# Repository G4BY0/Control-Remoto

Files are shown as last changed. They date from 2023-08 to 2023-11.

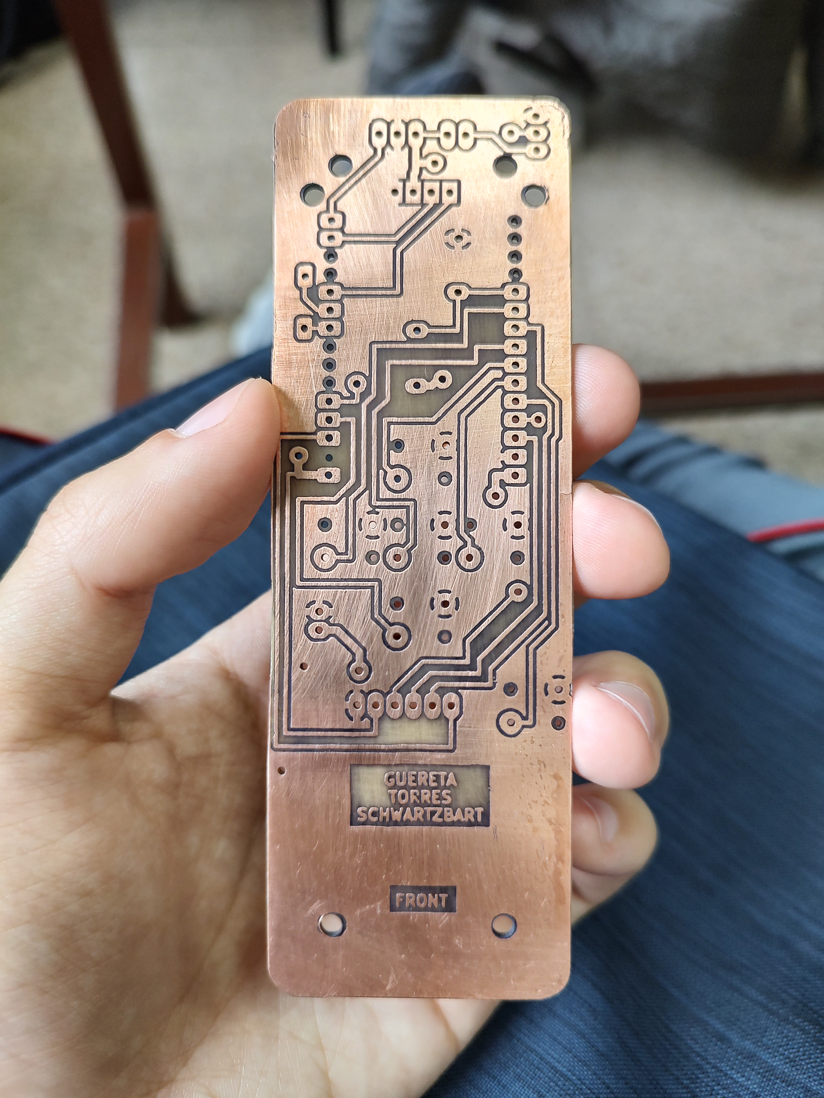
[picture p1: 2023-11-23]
hardware/PCB (KiCAD)/Front.jpg

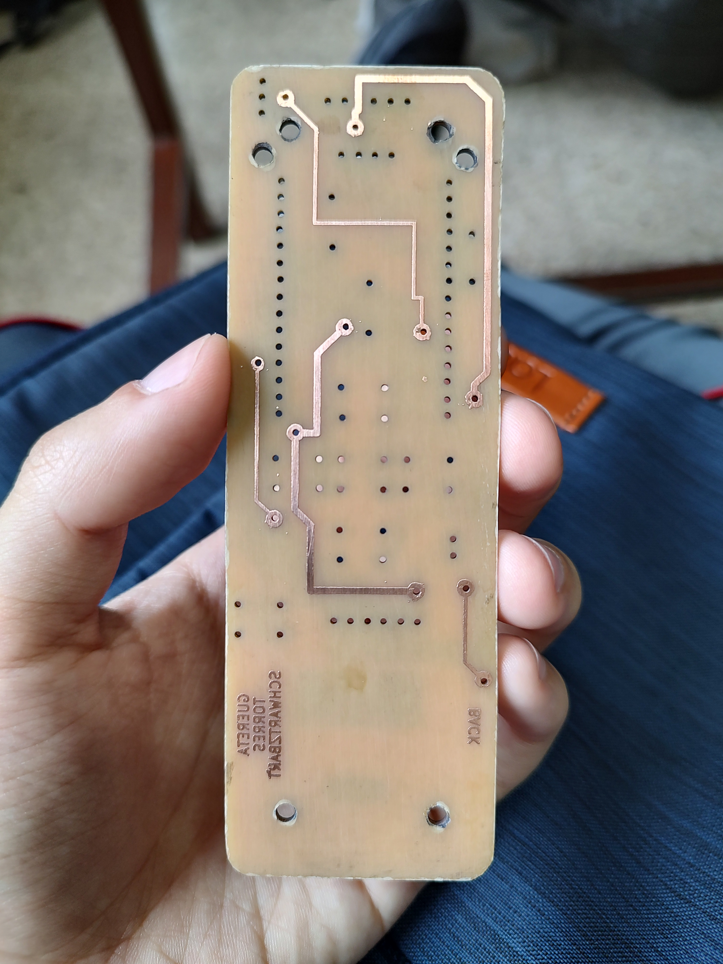
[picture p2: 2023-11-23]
hardware/PCB (KiCAD)/Back.jpg

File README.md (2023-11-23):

# Remote Controller

### A literal super universal remote controller, you can manipulate TVS, AIR CONDITIONERS, DECODERS and MORE.

The purpose of this project is to have in one room, one infrared remote for everything.

https://github.com/G4BY0/Control-Remoto/blob/af7007d788a45e271489a508236b302a6bf80a4f/Picture.jpeg

## Contents

  -[How it works?](#how-it-works?)
  -[Development Status](#development-status)
  -[Hardware](#hardware)
  -[Dependencies](#dependencies)

## How it works? (Software)

The structure of the stored Infrared signals is:

Example:

* Profile: LG TV
* Subprofile: Turn on

This kind of profiles are stored on the SD, they are separated in diferent files.

Example: LG_TV.db

This files have the binary of infrared signals with the name of their subprofiles.

## Development Status

Latest Stable Release    

Latest Development Release    

## Hardware

* [PCB](https://github.com/G4BY0/Control-Remoto/tree/main/hardware)
* Display Adafruit SH110X
* Six Botons
* [Nodemcu Esp32-S (4MB Flash Memory)](https://docs.ai-thinker.com/_media/esp32/docs/nodemcu-32s_product_specification.pdf)
* Module SD (3.3V, We modded it to work with that voltage)
* BC548 (Battery Medition)
* VS1838 (Infrared Receiver)
* Infrared LED (Infrared Emitter)
* LIPO Battery 3.7-4.2V
* Step Up 1.8v-4.2v to 5V (180mA)
* LIPO Charger USB-C Port
* 2N3904
* Resistors 10K, 10K, 630K (Battery Medition)
* [Six Keycaps](https://github.com/G4BY0/Control-Remoto/tree/main/hardware/STL's)
* [Case](https://github.com/G4BY0/Control-Remoto/tree/main/hardware/STL's)
* Cable USB-C for charging

## Dependencies

* [Adafruit BusIO](https://github.com/adafruit/Adafruit_BusIO)
* [Adafruit GFX Library](https://github.com/adafruit/Adafruit-GFX-Library)
* [Adafruit SH110X](https://github.com/adafruit/Adafruit_SH110x)
* [QRCode](https://www.adafruit.com/products/2471)
* [arduino-esp32](https://www.adafruit.com/products/2471)

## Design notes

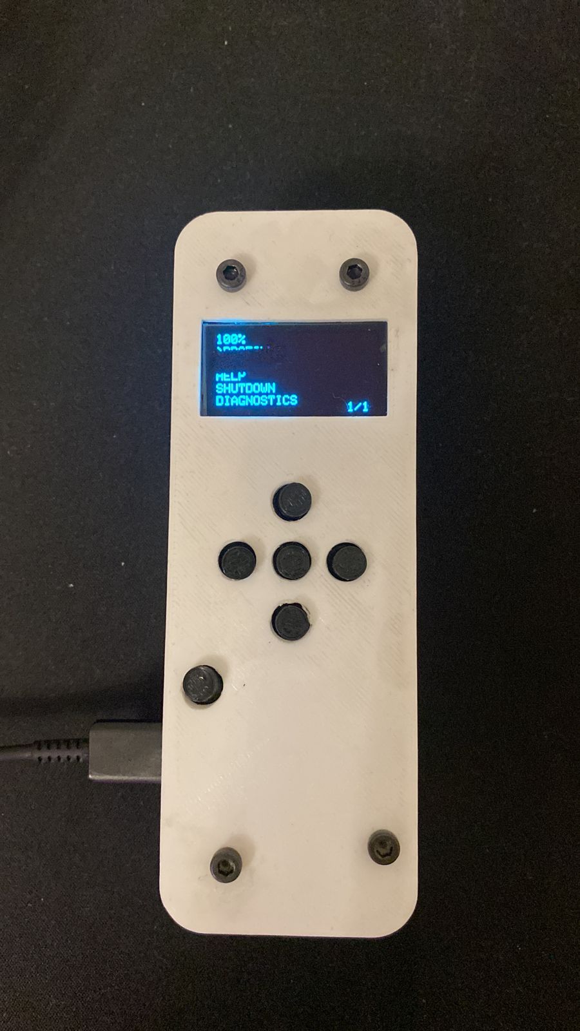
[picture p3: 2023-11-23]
Picture.jpeg

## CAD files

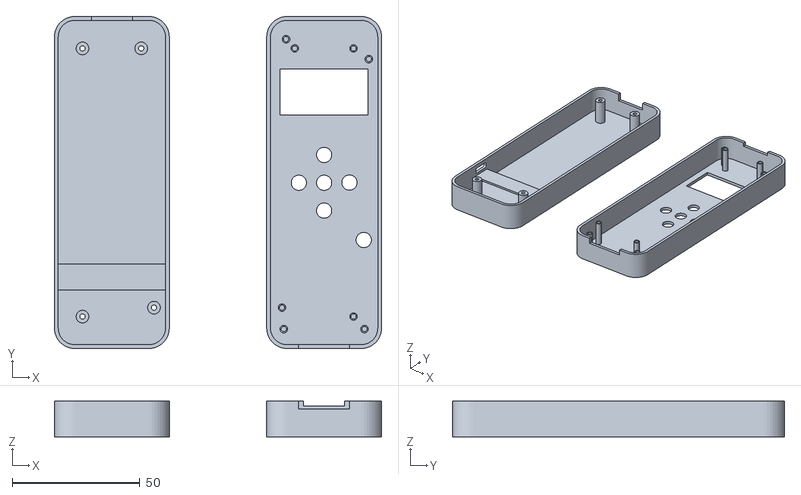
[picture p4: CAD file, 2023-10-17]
hardware/CASE/Gabinete.stl
128.1 x 130.0 x 14.0

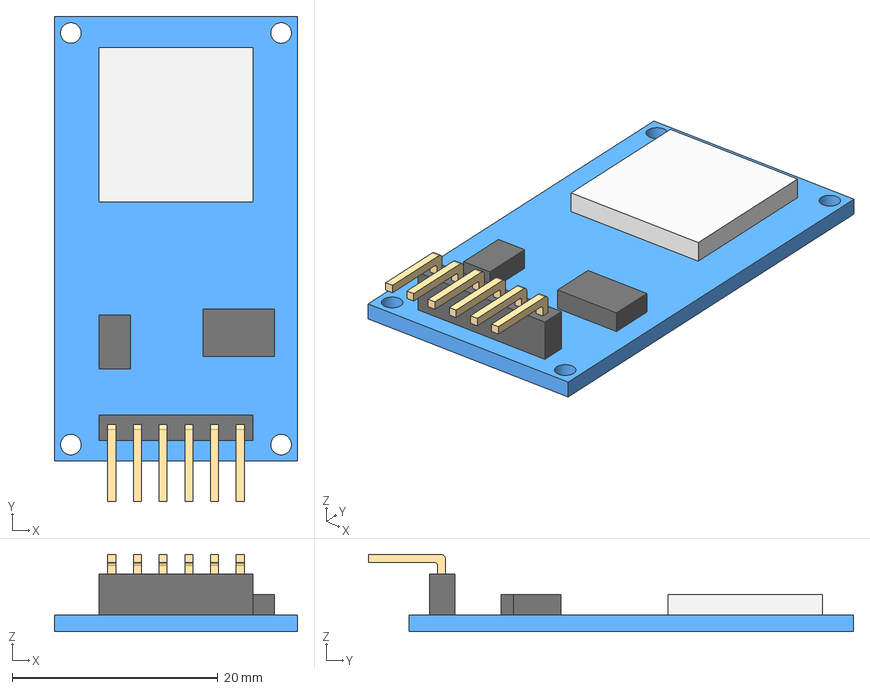
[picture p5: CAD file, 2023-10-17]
hardware/PCB (KiCAD)/modelos/micro_sdCard.step
23.6 x 47.1 x 7.50 mm

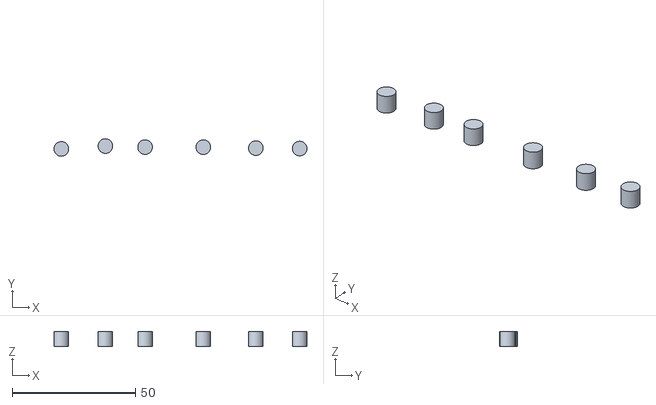
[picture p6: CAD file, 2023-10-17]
hardware/CASE/Keycaps.stl
102.7 x 7.11 x 6.00

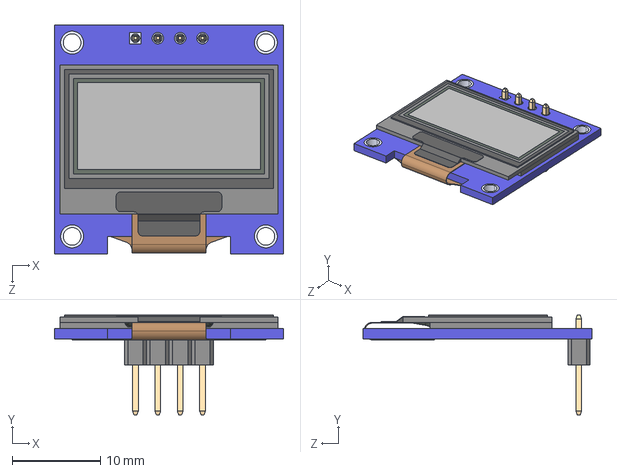
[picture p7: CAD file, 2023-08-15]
hardware/PCB (KiCAD)/modelos/DM-OLED096-636--3DModel-STEP-56544.STEP
26.0 x 11.3 x 26.0 mm
DM-OLED096-636_Module
DM-OLED096-636_Panel

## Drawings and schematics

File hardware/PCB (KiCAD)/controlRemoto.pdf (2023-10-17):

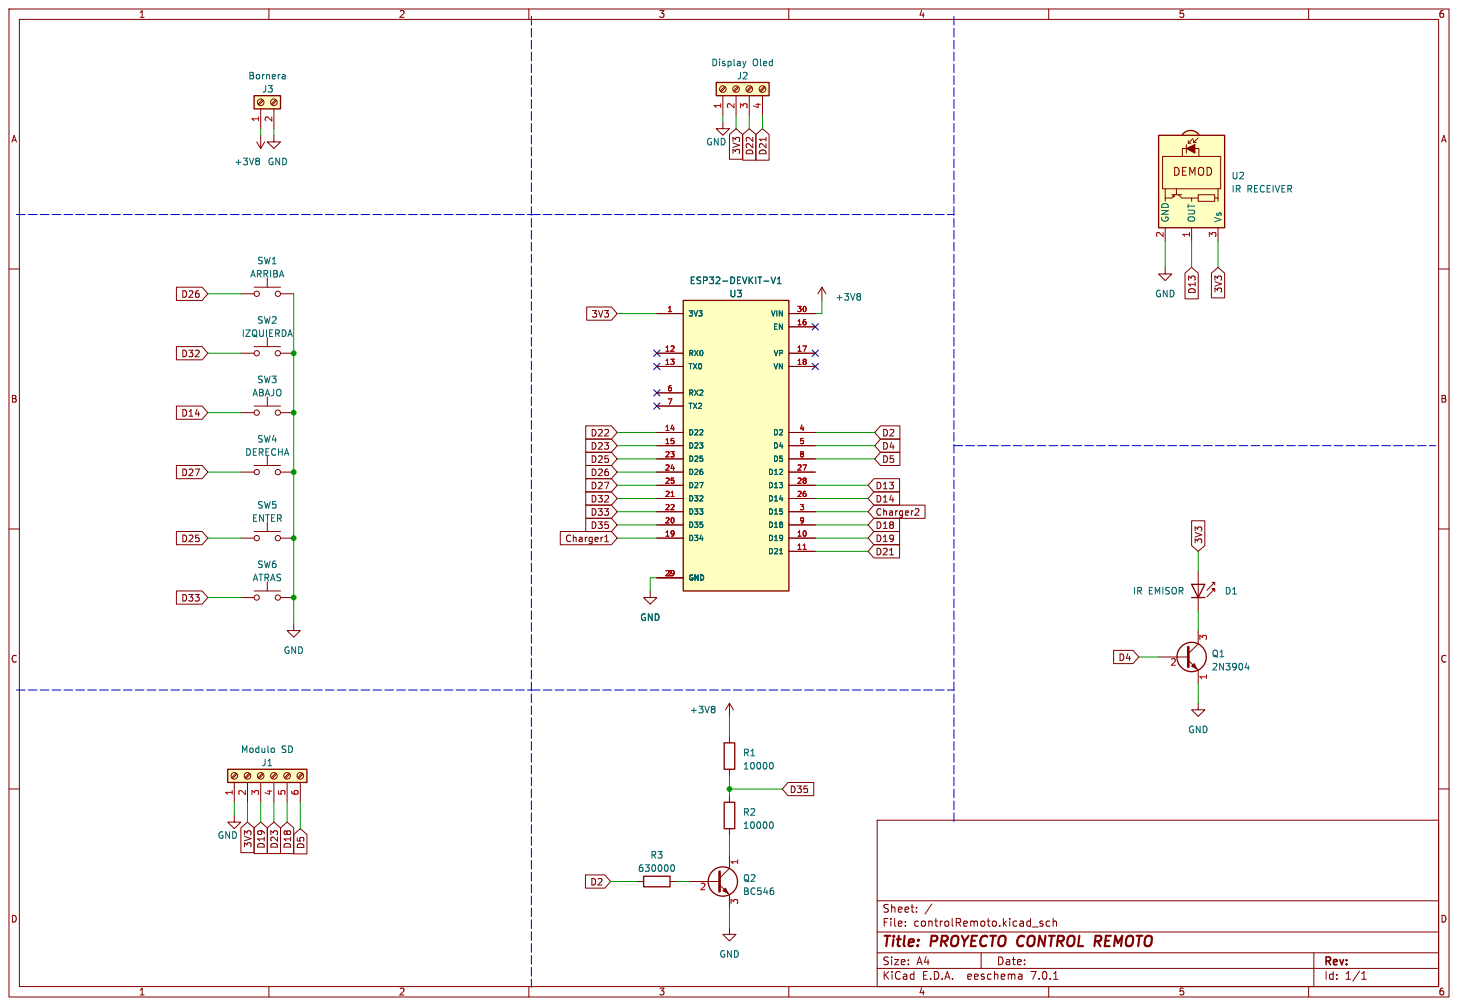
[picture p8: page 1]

File: controlRemoto.kicad_sch Sheet: / SW5 ENTER

Id: 1/1 Title: PROYECTO CONTROL REMOTO

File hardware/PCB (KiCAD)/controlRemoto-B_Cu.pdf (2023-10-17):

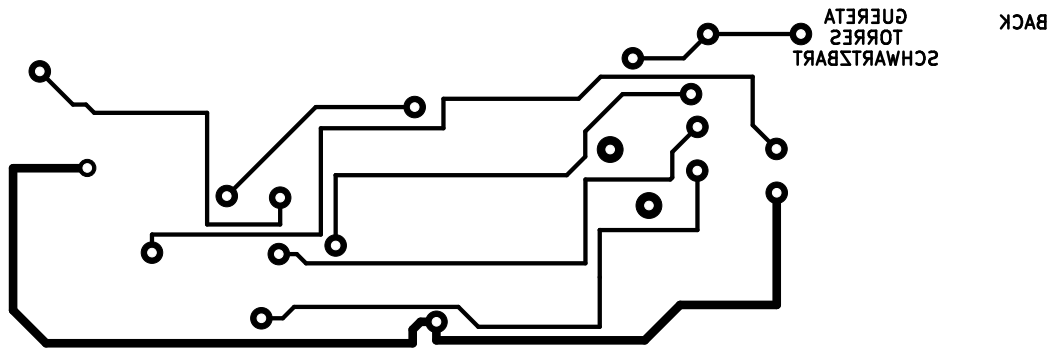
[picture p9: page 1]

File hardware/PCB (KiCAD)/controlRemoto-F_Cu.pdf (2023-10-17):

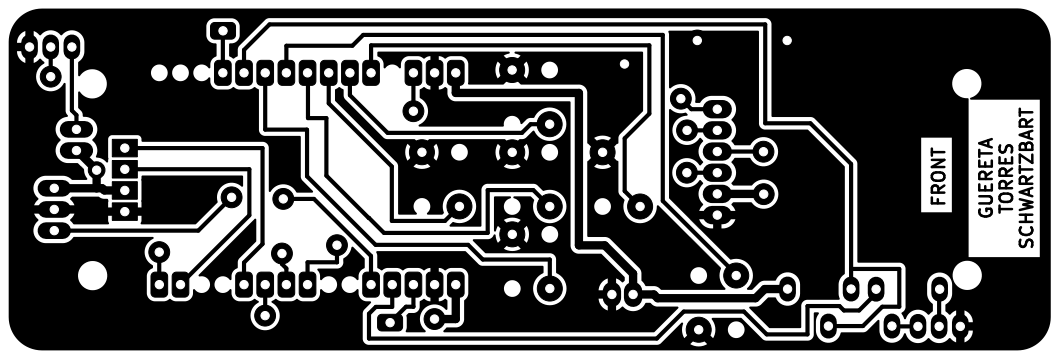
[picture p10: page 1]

GUERETA TORRES SCHWARTZBART FRONT

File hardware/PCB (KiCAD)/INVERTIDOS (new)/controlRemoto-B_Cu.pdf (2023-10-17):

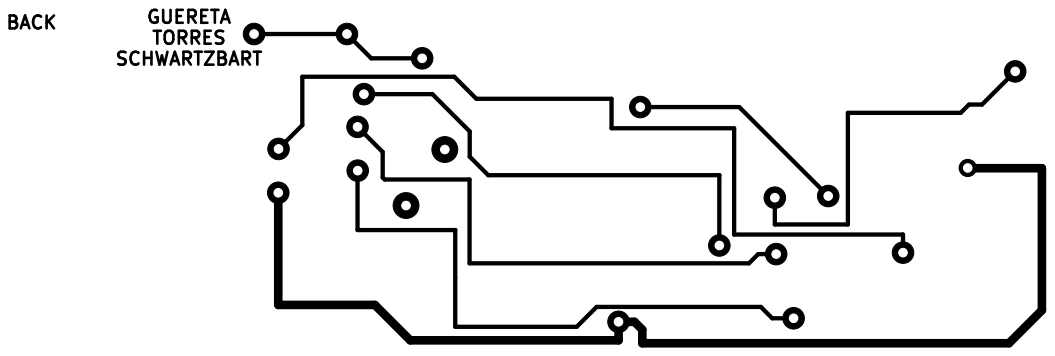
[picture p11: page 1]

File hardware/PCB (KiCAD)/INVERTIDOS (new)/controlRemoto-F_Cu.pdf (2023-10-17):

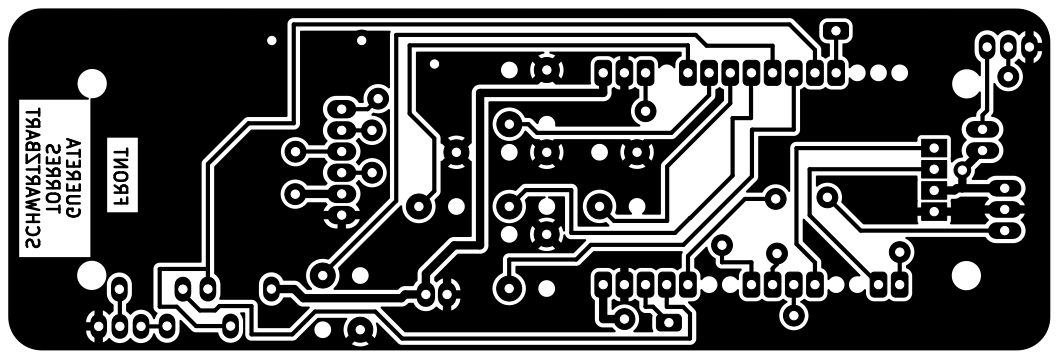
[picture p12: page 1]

TORRES GUERETA SCHWARTZBART FRONT

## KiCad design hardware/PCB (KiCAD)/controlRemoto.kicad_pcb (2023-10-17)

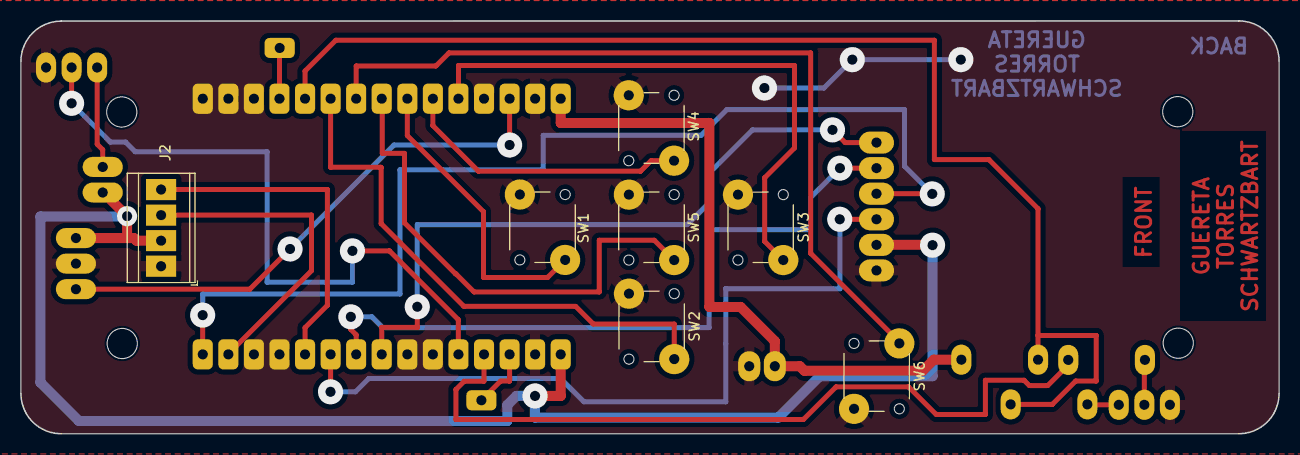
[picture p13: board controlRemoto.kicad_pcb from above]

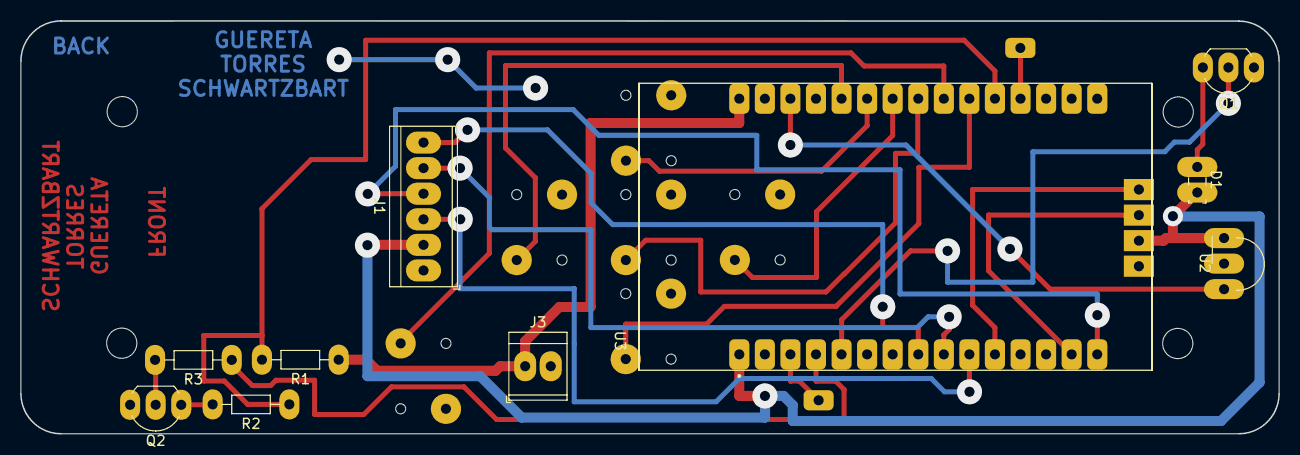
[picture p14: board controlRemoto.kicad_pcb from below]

Board: 2 copper layers, 125.0 x 41.0 mm, 17 parts (10 on the bottom side), 22 nets.

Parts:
D1: IR EMISOR; LED_SideEmitter_Rectangular_W4.5mm_H1.6mm
J1: Modulo SD; TerminalBlock_TE_282834-6_1x06_P2.54mm_Horizontal
J2: Display Oled; TerminalBlock_TE_282834-4_1x04_P2.54mm_Horizontal
J3: Bornera; TerminalBlock_TE_282834-2_1x02_P2.54mm_Horizontal
Q1: 2N3904; TO-92_Inline_Wide
Q2: BC546; TO-92_Inline_Wide
R1, R2: 10000; R_Axial_DIN0204_L3.6mm_D1.6mm_P7.62mm_Horizontal
R3: 630000; R_Axial_DIN0204_L3.6mm_D1.6mm_P7.62mm_Horizontal
SW1: ARRIBA; SW_PUSH_6mm_H4.3mm
SW2: IZQUIERDA; SW_PUSH_6mm_H4.3mm
SW3: ABAJO; SW_PUSH_6mm_H4.3mm
SW4: DERECHA; SW_PUSH_6mm_H4.3mm
SW5: ENTER; SW_PUSH_6mm_H4.3mm
SW6: ATRAS; SW_PUSH_6mm_H4.3mm
U2: IR RECEIVER; Vishay_MINIMOLD-3Pin
U3: ESP32-DEVKIT-V1; MODULE_ESP32_DEVKIT_V1

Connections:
3V3: D1.2 (A), J1.2, J2.2, U2.3 (Vs), U3.1 (3V3)
+3V8: J3.1, R1.1, U3.30 (VIN)
D2: R3.1, U3.4 (D2)
D4: Q1.2 (B), U3.5 (D4)
D5: J1.6, U3.8 (D5)
D13: U2.1 (OUT), U3.28 (D13)
D14: SW3.1, U3.26 (D14)
D18: J1.5, U3.9 (D18)
D19: J1.3, U3.10 (D19)
D21: J2.4, U3.11 (D21)
D22: J2.3, U3.14 (D22)
D23: J1.4, U3.15 (D23)
D25: SW5.1, U3.23 (D25)
D26: SW1.1, U3.24 (D26)
D27: SW4.1, U3.25 (D27)
D32: SW2.1, U3.21 (D32)
D33: SW6.1, U3.22 (D33)
D35: R1.2, R2.1, U3.20 (D35)
GND: J1.1, J2.1, J3.2, Q1.1 (E), Q2.3 (E), SW1.2, SW2.2, SW3.2, SW4.2, SW5.2, SW6.2, U2.2 (GND), U3.2 (GND), U3.29 (GND)
unnamed: D1.1 (K), Q1.3 (C)
unnamed: Q2.2 (B), R3.2
unnamed: Q2.1 (C), R2.2

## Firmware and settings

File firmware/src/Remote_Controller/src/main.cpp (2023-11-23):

//Copyright Grupo 11, Inc. All Rights Reserved.
/***********************************************
 * * * * * * * * * * * * * * * * * * * * * * * *
 * \file
 * Main.cpp (Main File)
 * 
 * * * * * * * * * * * * * * * * * * * * * * * *
***********************************************/
#warning "Project is in developing, it's not already yet!"

#include <Arduino.h>
#include <Wire.h>               // I2C
#ifdef ESP32
#include <Wifi.h>
#elif ESP8266
#include <ESP8266WiFi.h>
#endif
#include <NTPClient.h>
#include <WiFiUdp.h>
#define WIFI_ON

#include <SPI.h> 
#include "System.h"
#include "Storage/Config.h"
#include "Modes/Modes.h"

#define DEBUG

SPIClass spi; // Medio de Comunicacion con el Almacenamiento

//Velocidad del Monitor Serial
#define SERIAL_BAUDRATE 115200
//Frecuencia de Actualizacion del Clock (En Milisegundos)
#define REFRESH_CLOCK 500 
// Retocar macro en caso de querer establecer cuanto se pone el modo apagado luego de estar ese tiempo en el modo SLEEPING (En Segundos)
#define SLEEP_TIME_WAITING_TO_SHUTDOWN (5U * 60U)   // 5 minutos en segundos

// Retocar macro en caso de querer establecer cuanto tiempo el usuario debe mantener el boton back para poner el modo SLEEPING (En Segundos)
#define SLEEP_TIME_BUTTONPRESSING (5U)

#define CLOCK_ON
#define WIFI_ON  
//#define BLUETOOTH_ON

#define SSID_IN         "TP-LINK_4F48"        //SSID del access point en el que se conectara el servicio WiFi
#define PASSWORD_IN     "51807511"            //PASSWORD del access point en el que se conectara el servicio WiFi

//(Desarrollo) Pagina Web
#define SSID_OUT        "Remote_Controller"   //SSID del access point que se generara
#define PASSWORD_OUT    "Authors:GMJ"       //PASSWORD del access point que se generara

void setup(){
    
    Serial.begin(SERIAL_BAUDRATE , SERIAL_8N1 );

    // Configuracion de protocolo de comunicacion para el almacenamiento
    spi=SPIClass(VSPI); 
    spi.begin();
    
    // Inicializacion del sistema del display
    displayBegin();     Serial.println(F("Display Inicializado."));

    // Inicializacion del sistema de botones
    buttonsBegin();     Serial.println(F("Botonera Inicializada."));

    // Inicializacion del sistema de almacenamiento
    SDBegin();          Serial.println(F("Almacenamiento Inicializado."));

    // Inicializacion del sistema del infrarrojo
    infraredBegin();    Serial.println(F("Infrared Inicializado."));
    
    // configSaved(); // (Canceled) De momento cancelado hasta nuevo aviso

    // Espero a que todos los procesos terminen para inicializar
    Serial.flush(); yield();
    /*
    // Task para correr el programa principal
    xTaskCreate(
        Task_Idle,                      // Funcion codigo del Task
        "Task_Idle",                    // Nombre del Task 
        100024U,                        // Reserva de espacio en la Pila
        NULL,                           // Argumentos
        tskIDLE_PRIORITY,               // Prioridad
        &handleIdle                     // Handle 
    );
    */
    // Crear tarea del Watchdog Timer
    xTaskCreate(
        Task_WatchDogTimer,             // Funcion codigo del Task
        "Task_WatchDogTimer",           // Nombre del Task
        configMINIMAL_STACK_SIZE + 256U,// Reserva de espacio en la Pila
        NULL,                           // Argumentos
        tskIDLE_PRIORITY + 2U,          // Prioridad
        NULL                            // Sin Handle
    );

    // Task para preguntar si el usuario esta activo de forma dinamica 
    xTaskCreate(
        Task_AFK,                       //Funcion codigo del Task
        "Task_AFK",                     //Nombre del Task 
        configMINIMAL_STACK_SIZE + 256U,//Reserva de espacio en la Pila 
        NULL,                           //Argumentos
        tskIDLE_PRIORITY + 1U,          //Prioridad
        &handleSleep                    //Handle   
    );

    // Task para preguntar si se desea un reinicio de emergencia
    xTaskCreate(
        Task_emergencyRestart,              //Funcion codigo del Task
        "Task_AskingForEmergencyRestart",   //Nombre del Task 
        configMINIMAL_STACK_SIZE + 256U,    //Reserva de espacio en la Pila 
        NULL,                               //Argumentos 
        tskIDLE_PRIORITY + 2U,              //Prioridad
        NULL                                //Handle   
    );

    UI.show = true;
    UI.show_battery = true;
    UI.show_storage = false;
    UI.run(); // Task para la User Interface

    // Iniciar el scheduler de FreeRTOS
    //vTaskStartScheduler(); // Genera un core dump si se permite el uso del void loop() Asegurarse de usar si es que no se usa el void loop() (Generado por el Watch Dog Timer)

}

//Puesto unicamente por el framework de arduino. El sistema esta montado en Tasks gracias a FreeRTOS
void loop(){ MODE::hub(); } //El Idle esta ubicado en System.h (Programa principal)

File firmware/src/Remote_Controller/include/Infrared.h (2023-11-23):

//Copyright Grupo 11, Inc. All Rights Reserved.
/***********************************************
 * * * * * * * * * * * * * * * * * * * * * * * *
 * \file
 * Manejo de las señales infrarrojas 
 * 
 * * * * * * * * * * * * * * * * * * * * * * * *
***********************************************/
#ifndef INFRARED_H
#define INFRARED_H

#include <Arduino.h>
#include <cstdint>
#include <memory>
#include <algorithm>
#include "PIN.h"
#include <IRsend.h>
#include <IRrecv.h>
#include <IRremoteESP8266.h> // Tambien tiene soporte para placas espressif32!
#include <IRutils.h>

#include "PIN.h"

// The GPIO an IR detector/demodulator is connected to. Recommended: 14 (D5)
// Note: GPIO 16 won't work on the ESP8266 as it does not have interrupts.
// Note: GPIO 14 won't work on the ESP32-C3 as it causes the board to reboot.
constexpr uint16_t kRecvPin = PIN::InfraredReceiver::DATA;
// GPIO to use to control the IR LED circuit. Recommended: 4 (D2).
constexpr uint16_t kIrLedPin = PIN::InfraredTransmitter::DATA;
// The Serial connection baud rate.
// NOTE: Make sure you set your Serial Monitor to the same speed.
constexpr uint32_t kBaudRate = 115200;
// As this program is a special purpose capture/resender, let's use a larger
// than expected buffer so we can handle very large IR messages.
// i.e. Up to 512 bits.
constexpr uint16_t kCaptureBufferSize = 1024U;
// kTimeout is the Nr. of milli-Seconds of no-more-data before we consider a
// message ended.
constexpr uint8_t kTimeout = 50U;  // Milli-Seconds
// kFrequency is the modulation frequency all messages will be replayed at.
constexpr uint16_t kFrequency = 38000U;  // in Hz. e.g. 38kHz.

// Storage for the recorded code
// Estructura de almacenamiento de datos del infrarrojo
struct storedIRDataStruct {
  decode_results results;
  char nameSubProfile[30] = {'\0'}; // Nombre del subperfil + Inicializacion
};

/*! @brief Inicializacion de infrarrojos
    @note Arduino por defecto establece como entrada los pines digitales*/
void infraredBegin(void);

/*! @brief Inicia el proceso para recibir señales infrarrojas
    @note Crea una estructura que almacena cadena binaria (guardada en hexadecimal), numero de bits, etc  
*/
void Receive_start(void);

/*! @brief Checkea si es correcta la cadena binaria recibida
    @note Compara con la escructura del objeto IrReceiver.decodedIRData
    @returns Si pasa las pruebas retorna EXIT_SUCCESS, sino EXIT_FAILURE.
*/
bool Receive_check(void);

/*! @brief Checkea si es correcta la cadena binaria recibida
    @note Compara con la escructura del objeto IrReceiver.decodedIRData
*/
void Receive_stop(void);

/*! @brief Envia señal infrarroja
    @param aIRDataToSend recibe estructura con la data de la señal
    @note usara la estructura recibida referencia para el envio de la informacion
*/
void sendCode(std::shared_ptr<storedIRDataStruct> IRData);

/*! @brief Hace una copia de datos del infrarrojo usando lo que tiene guardado la instancia IrReceiver
    @returns Retorna puntero inteligente de accesso unico del objeto de la informacion recibida
    @note Retorna la copia de datos
*/
std::shared_ptr<storedIRDataStruct> storeCode( const char* subprofileName );

#endif //Infrared_h

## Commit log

2023-03-07 Inicio de Proyecto
    Estableciendo parámetros iniciales, ordenando y usando herramientas planteadas en la materia Proyecto Final
2023-03-07 Desarrollado en clase
    Plasme lo desarrollado en clase para luego continuarlo en el instituto
2023-03-07 desarrollo en clase + tutorial
    Introduccion de clases de gaby a melvin y joaco, melvin propuso buenas ideas de la interfaz del tft "los menus"
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2023-04-04 Developing
    Desarrollo clase 04/04/23 CON 5000 PROBLEMAS DE INTERNET
    [main.cpp]
2023-04-10 Developing
    Desarrollando y separando de manera intuitiva el codigo para facil comprension
2023-04-10 Updateado lo que joaco me corrigio
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2023-04-20 Developing
    Subo cambios por si hay algun boludo que tiene ganas de molestar, dejaron el celu en porteria porque me lo olvide en el auto y me voy un toq, ahora sigo desarrollando en un rato.
2023-04-20 Developing
    me olvide de incluir un archivo q tmb es para actualizar
2023-04-24 Ordenando
    Ordenando y poniendo Pie de paginas a los archivos indicando lo que esta desarrollado en cada uno
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2023-05-05 Discutiendo
    Discutiendo como va a ser el desarrollo de los subperfiles y que en la version beta del proyecto, el nombre de los subperfiles va a estar limitado hasta 12 caracteres.
2023-05-11 Developing
    Desarrollando crear y eliminar subperfiles, falta desarrollar un poco mas y tambien el apartado del almacenamiento de los subperfiles para agregar y eliminar
2023-05-14 Cursor
    Una creación rápida del Writter hasta que Joaco desarrolle el pensado para el proyecto, por lo tanto se usara este para la versión Pre-Alpha, habría que desarrollar la funcion que retorne el String. 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
2023-05-14 Cursor WritterV2 + Developing
    Desarrollo de otra clase de Writter y desarrollo en el codigo
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2023-05-16 Cambio de pines en el infrarrojo
    Un cambio pequeño pero a la vez crucial
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2023-05-21 Developing & Searching for Errors
    Sigo buscando el error de indefiniciones cuando se compila, agregue un par de features mas
    [Infrared.h, main.cpp]
2023-05-21 Desarrollando y fixeando bugs
    Problema al terminar el compilado:
    Advanced Memory Usage is available via "PlatformIO Home > Project Inspect"
    Error: The program size (44552 bytes) is greater than maximum allowed (32256 bytes)
    RAM: [====*** [checkprogsize] Explicit exit, status 1
    ======] 151.8% (used 3109 bytes from 2048 bytes)
    Flash: [==========] 138.1% (used 44552 bytes from 32256 bytes)
    [Infrared.h, main.cpp]
2023-05-22 Optimizing
    - Se genero una banda de optimización gracias a que las cadenas de caracteres se pueden almacenar en la memoria flash en vez de la ram (utilizando por ejemplo: F() que devuelve: const __FlashStringHe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
    "F() se utiliza para almacenar cadenas de texto en la memoria de programa (flash) en lugar de la memoria RAM. El tipo devuelto por F() es const __FlashStringHelper*, que es un tipo especial definido 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
    La principal diferencia radica en la ubicación de almacenamiento de la cadena de texto. Mientras que const char* almacena la cadena en la memoria RAM, F() almacena la cadena en la m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
2023-05-22 Revert "Merge branch 'main' of https://github.com/G4BY0/Control-Remoto"
    This reverts commit 837ff85419d4052589fc81d3b128047e9ac2cd6c, reversing
    changes made to 7caad8b457a1bfaa03c37a63b954458544b7a994.
    [Infrared.h, main.cpp]
2023-05-22 Revert "Revert "Merge branch 'main' of https://github.com/G4BY0/Control-Remoto""
    This reverts commit 4b9f240cd9d582058136f83fae59486e599da04a.
    [Infrared.h, main.cpp]
2023-05-22 Optimizando
    Optimizando las mierdas que Guereta deja. Miranda nos sirvió de gran ayuda
2023-05-22 Coniguration for Atmega2360
    Configurando el proyecto para simular en el Arduino Mega 2560, ya que con el uno hay desbordamiento de memoria flash y en proteus la libreria "Simulino" no abarca el arduino leonardo.
2023-05-26 Seteando Configs
    - La librería SD como es incompatible con otras arquitecturas que no son AVR, la desinstale y en caso de usar la placa que tenga AVR se usará esa, sino la otra.
    [Infrared.h, main.cpp]
2023-05-31 Developing & Correcting Issues
    Arreglado el problema de reinicio en el setup, pero luego hay otro problema que un nucleo hace dump y resetea el sketch... Solucionar pronto
    Guru Meditation Error: Core 1 panic'ed (LoadProhibited). Exception was unhandled.
    Core 1 register dump:
    PC : 0x40087818 PS : 0x00060e30 A0 : 0x800d8014 A1 : 0x3ffb2190
    A2 : 0x00000002 A3 : 0x00000000 A4 : 0x000000ff A5 : 0x0000ff00
    A6 : 0x00ff0000 A7 : 0xff000000 A8 : 0x80104904 A9 : 0x3ffb2150
    A10 : 0x00000001 A11 : 0x00000006 A12 : 0x800d88a9 A13 : 0x3ffbf4dc
    A14 : 0x00000000 A15 : 0x3ffc33b4 SAR : 0x00000002 EXCCAUS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
    [main.cpp]
2023-06-01 IRremote Issues
    Debido a que vamos a usar la placa ESP32S de la marca nodemcu, IRremote no dispone de compatibilidad al esp32... entonces se debera usar otra lamentablemente.
    Esto da lugar a que hay que desarrollar en el apartado de Profiles y Infrared.
    [Infrared.h, main.cpp]
2023-06-05 Dev
    Developing & Correcting Issues
    [Infrared.h]
2023-06-06 Correcting Issues
    corrigiendo errores en el colegio, sin melvin lamentablemente. porque falto y no aviso >>:(((((
    [main.cpp]
2023-06-12 WritterV2 Issue
    Corregido issue en clase, falta desarrollo para cuando se termine de escribir el string, el lugar donde marca en el serial: String finalizado es el caso del switch donde se selecciona la opcion "snd"
2023-06-14 Ordenando y Corrigiendo Errores
    Corrigiendo errores, ordenando y viendo que onda lo del cursor
2023-06-16 Developin Alone :(
    Hoy falto mi equipo, estoy solo en el banco, pero mientras desarrollaba los sentia q me estaban viendo y apoyando asi que los agrego como colaboradores :)
    No pude probar lo del cursor en el programa porque el hardware lo tiene Melvin porque yo soy un salame q se lo olvido ayer en gimnasia... pero estuve corrigiendo algunos sectores de codigo que podian dar lugar a que hayan bugs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
2023-06-21 Desarrollo CursorUltimate
    Desarrollando y todavía intentando rescatar el CursorV2 (descubri una forma de hacerlo pero lo tengo que checkear y son las 22:53)
2023-06-22 Developing & Correcting Issues
    En la mañana de hoy se agrego la herramienta std::vector para el movimiento dinamico (en la memoria heap) de los nombres de los perfiles y subperfiles, hay q retocar un par de cosas del Writter y del movimiento del usuario en Interface.cxx que especifique como comentarios, 2 comentarios me faltaron pero ya me tengo q ir a comer y desp sigo desarrollando :)))))))))))))))))
2023-06-23 Comments
    Comentando algunas cosas que no pude comentar en su momento debido a la perdida de cordura que me causaba el tema de que no funcionaba el modulo SD. ufffffff.... 😌😌😌😌😌
2023-06-26 Implementation of Smart Pointers
    Todavia necesitamos seguir desarrollando, hay un bug que coliciona el sistema cuando se finaliza el nombre del nuevo subperfil. averiguar luego, y tambien hay que acomodar que tipo de puntero inteligente se deberia usar, de principio todos son shared_ptr
    [Infrared.h]
2023-06-26 Developing
    Desarrollando pero lo pedido en el pasado commit no. Queda pendiente
2023-06-28 Comentando y optimizando
    Despues de tener la prueba de seba y la de Falduti q no me termino tomando
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2023-06-29 Una cosita mas
    Me olvide de cambiarle el nombre a un archivo
2023-06-29 Developing
    Viendo donde esta el problema de lo de los strings de los directorios de los archivos, todavia no fue resuelto
2023-07-01 Desarrollando
    Mañana sigo viendo q es lo que cause el problema a la hora de almacenar el infrarrojo solo la información, el resto joya. luego de resolver lo del almacenamiento hay que ver de si funciona cuando lo retira y si lo manda y ya estaría terminado el codigo
    [Infrared.h]
2023-07-02 Correcting Issues
    Errores arreglados:
    - QR Performante (cree una función que recibe un string, y en base como funciona el QR, entrando en menos detalle cuando se decodifica el QR se recibe el string y ese string lo que hace el celu generalmente es pegarlo en un buscador web, yo en el codigo proporcione pasarle como string el URL del drive de la carpeta HELP. Tutorial: https://www.youtube.com/watch?v=sSSpmnxdzPM)
    - Arregle los bugs del WritterV2 de snd que cuando estaba en mayúscula o símbolos no dejaba marcar como terminado el string.
    - No encontré el por que no abre el archivo del Perfil para almacenar el Subperfil recibido. Después de eso vendría checkear si funca retirarlo del alma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
    [Infrared.h, main.cpp]
2023-07-03 Changing Libraries + Ordering + Correcting Issues + Development
    Cambiazo de librería de Arduino_IRremote a IRremoteESP8266 (que soporta también placas esp32) hice un test con el aire acondicionado (un example) y con el de Arduino_IRremote tiraba algo de timer error y desp prob el IRremoreESP8266 y funca joya, tengo que ver por que no abre el archivo para almacenar la señal recibida a la hora de guardar. Todavía no lo encontré que es lo que puede ser
    Cosas a hacer:
    - Buscar el bug de almacenamiento del sub perfil
    - Terminar de desarrollar lo del sleeping Mode
    [Infrared.h, main.cpp]
2023-07-03 Feature Sleep
    - Ahi esta el feature de sleep mode, estaría bueno ponerle una imagen de una luna corte de sleeping o algo asi. vi un video piola que lo hace: https://www.youtube.com/watch?v=0KGMFhFQ0YY
    https://animator.wokwi.com/
    Pero prioridad N°1 ahora es encontrar el bug que no me deja almacenar el subperfil.
2023-07-03 dev
    me teng oq ir de excursionm subo esto rapido pero noe esta terminado
2023-07-07 Arreglando Cositas + ShutDown Mode
    Arreglado lo de almacenar el subperfil. Ahora hay que ver lo de cuando lo retira del almacenamiento los subperfiles.
    Arreglado lo del QR que estaba recortado cuando se codificada el string a QR, y es modificando la versión del mismo. El QR puede tener diferentes versiones y algunas permiten codificar mas información que otras.
    + Feature de modo Sleeping Profundo (Agregue unas lib para ver q onda porque ya hay un par desarrolladas, me falto agregar al modo shuTdown de bajar la velocidad del procesador. tambien estaba pensando en una idea y es crear además de lo futuro del multithreading (task del loop, task de la batería, task de preguntar si el botón b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
    [main.cpp]
2023-07-10 Dev
    - Agregado los Tasks de batería y Sleep (multithreading)
    - Agregue en el Cursor que si se presiona derecha es como si tocara ENTER y si tocara el botón izquierda es como si tocara BACK (es mas intuitivo y no cambia nada ponerlo)
    - (IDEA) Agregar un reloj en el menú principal porque el nodemcu esp32 tiene un RTC incorporado
    - (IDEA) Lo de placas AVR queda descartado por el momento, luego si pinta lo hacemos compatible para este tipo de placas.
    - (BUG) todavía no fue corregido lo del cursor de ir de abajo del todo al primero del todo
    - (BUG) Lo de retirar del almacenamiento el perfil todavia no arreglado
    - Separados el modo ShutDown (Apagado pero en espera) y Sleep (Dormido y en espera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
    [Infrared.h, main.cpp]
2023-07-10 Issues
    -Algunos errores por compatibilidades.
    - Linea 168 main.cpp Comentario explicado:
    //vTaskStartScheduler(); // Genera un core dump si se permite el uso del void loop() Asegurarse de usar si es que no se usa el void loop()
    - Mañana tengo que reeplantear una forma de como extraer los subperfiles porque no esta bien plataneada la logica y por eso no lee los subperfiles del almacenamiento
    [main.cpp]
2023-07-11 Arreglado lo del Watch Dog Timer
    Nuevo task que refresca el Timer del Watch Dog
    [main.cpp]
2023-07-11 Dev
    Retoquesitos del dia de hoy.
    ver que onda lo del perfil invisible y eso. me parece que ya no sucede mas por lo solucionado en el anterior comit. Lo del Watch Dog Timer Solution
2023-07-11 Dev
    Corrigiendo cosas
    - Problema del perfil invisible
    - Llego a mi casa y testeo con mi aire de mucho mas cerca porque no tenemos el transistor para el emisor
    - Descargue la libreria de RTC para usar el que tiene adentro la placa
    [main.cpp]
2023-07-12 Dev
    Terminado, abría q retocar los bugs que tiene el cursor pero funca
    [main.cpp]
2023-07-12 DEV
    Developing
    -No llego a explicar porque ya nos tenemos que ir
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2023-07-14 DEV
    corrigiendo errores del Wifi y ma;ana a la ma;ana lo testeo para ver que onda
    [main.cpp]
2023-07-14 DEV
    viendo el consumo de cada task y cviendo lo de la hora y lo del cursor que muestre en que pagina me encuentro
2023-08-01 Guereta y Jesucristo
    Reordene todo el codigo. todos los tasks fueron ordenados como correspondían. hay archivos como System que mas que nada controlan lo que vendría a ser el sistema en si. El idle hay un tema porque fun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
2023-08-02 Correcting Bugs
    Arregle bugs de cuando tocas boton back que crasheaba
    [UserInterface.cpp, main.cpp]
2023-08-07 Correcting Bugs
    Corrigiendo Bugs y ordenando un toq las cosas y comentando
    [System.cpp, System.h, UserInterface.cpp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]
2023-08-10 Viendo la movida de los iconos para la UI
    Viendo que onda
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2023-08-14 Cambiazo a la UI
    -El tiempo se mostrara solo si se logra establecer conexion wifi
    -(dev) la bateria junto a su nivel en porcentaje de carga, se mostrar el simbolito
    -(dev) se deberia mostrar el porcentaje de la sd junto al dibujito. si no esta conectada ninguna SD deberia mostrar otro dibujito
2023-08-14 Dev
    Ordenando desarrollando y corrigiendo cosas. nuevo ordenamiento para el hub:
    -Profiles
    -Edit
    -Help
    -ShutDown
    -Diagnostics
2023-08-15 Integración del PCB
    Empezando a incorporar parte del hardware al repositorio.
    [DM-OLED096-636--3DModel-STEP-56544.STEP, controlRemoto.kicad_pcb, controlRemoto.kicad_sch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]
2023-08-29 Editando PCB
    Haciendo pequeños cambios al PCB y subiendo los pdf invertidos para su fabricación.
    [controlRemoto.kicad_pcb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]
2023-10-08 Update de pinout
    Tuvimos un problema cuando quisimos usar el HSPI del nodemcu esp32s, entonces tuvimos que rediseñar la placa y al final terminamos usando VSPI para evitar usar el pin GPIO12, que es para strapping y causaba problemas :(
2023-10-09 Actualizacion + correccion de bugs
    problemas solucionados:
    -no funciona receiver -> cuando quiero agregar un subperfil a un perfil no lee la se;al
    -cuando creo un perfil y quiero agregar un subperfil al toque se cancela
    -cuando entra en el modo shutdown se ve la bateria aun y cuando toco un boton no vuelve a arrancar el sistema, como si estuviese congelado
    -diagnostics el problema de ese modo es que muestra la cantidad de espacio libre de memoria erronea
    [Infrared.h, System.cpp, System.h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]
2023-10-17 Correcting Issues
    Único problema sin resolver:
    no funciona DELETE SUBPROFILE
    bateria clavada en 100%
    cuando vas para arriba de create profile se crashea (muy de cajeta darse cuenta)
    Cualquier cosa, mantener presionado boton back durante masomenos 5 segundos y se resetea sistema. si ven q no resetea o algo -> es por la alimentacion
    [Infrared.h, System.cpp, System.h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]
2023-10-17 Añadiendo archivos STL's y PCB
    Los respectivos STL del gabinete y keycaps y también el KiCAD del PCB.
    [Gabinete.stl, Keycaps.stl, controlRemoto.kicad_pcb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]
2023-10-29 Problemas con el pin 13 (quemado)
    tomando medidas, cambie el pin del receiver al 15
    [Infrared.h, UserInterface.cpp]
